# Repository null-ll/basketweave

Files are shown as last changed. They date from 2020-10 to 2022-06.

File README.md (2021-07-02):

# Basketweave
Basketweave

Through-hole Alice-style keyboard with arrow keys and a rotary encoder

### Default Layout
Default Layout
> View on [Keyboard Layout Editor](http://www.keyboard-layout-editor.com/#/gists/9b58a2c896b3cc25a28ef1dc43d93095) - for reference only

### BOM and Build Guide
[Build Guide](doc/build.md)

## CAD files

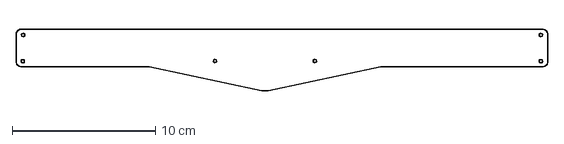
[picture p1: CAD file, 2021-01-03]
acrylic_guard.dxf
37.1 x 4.29 cm

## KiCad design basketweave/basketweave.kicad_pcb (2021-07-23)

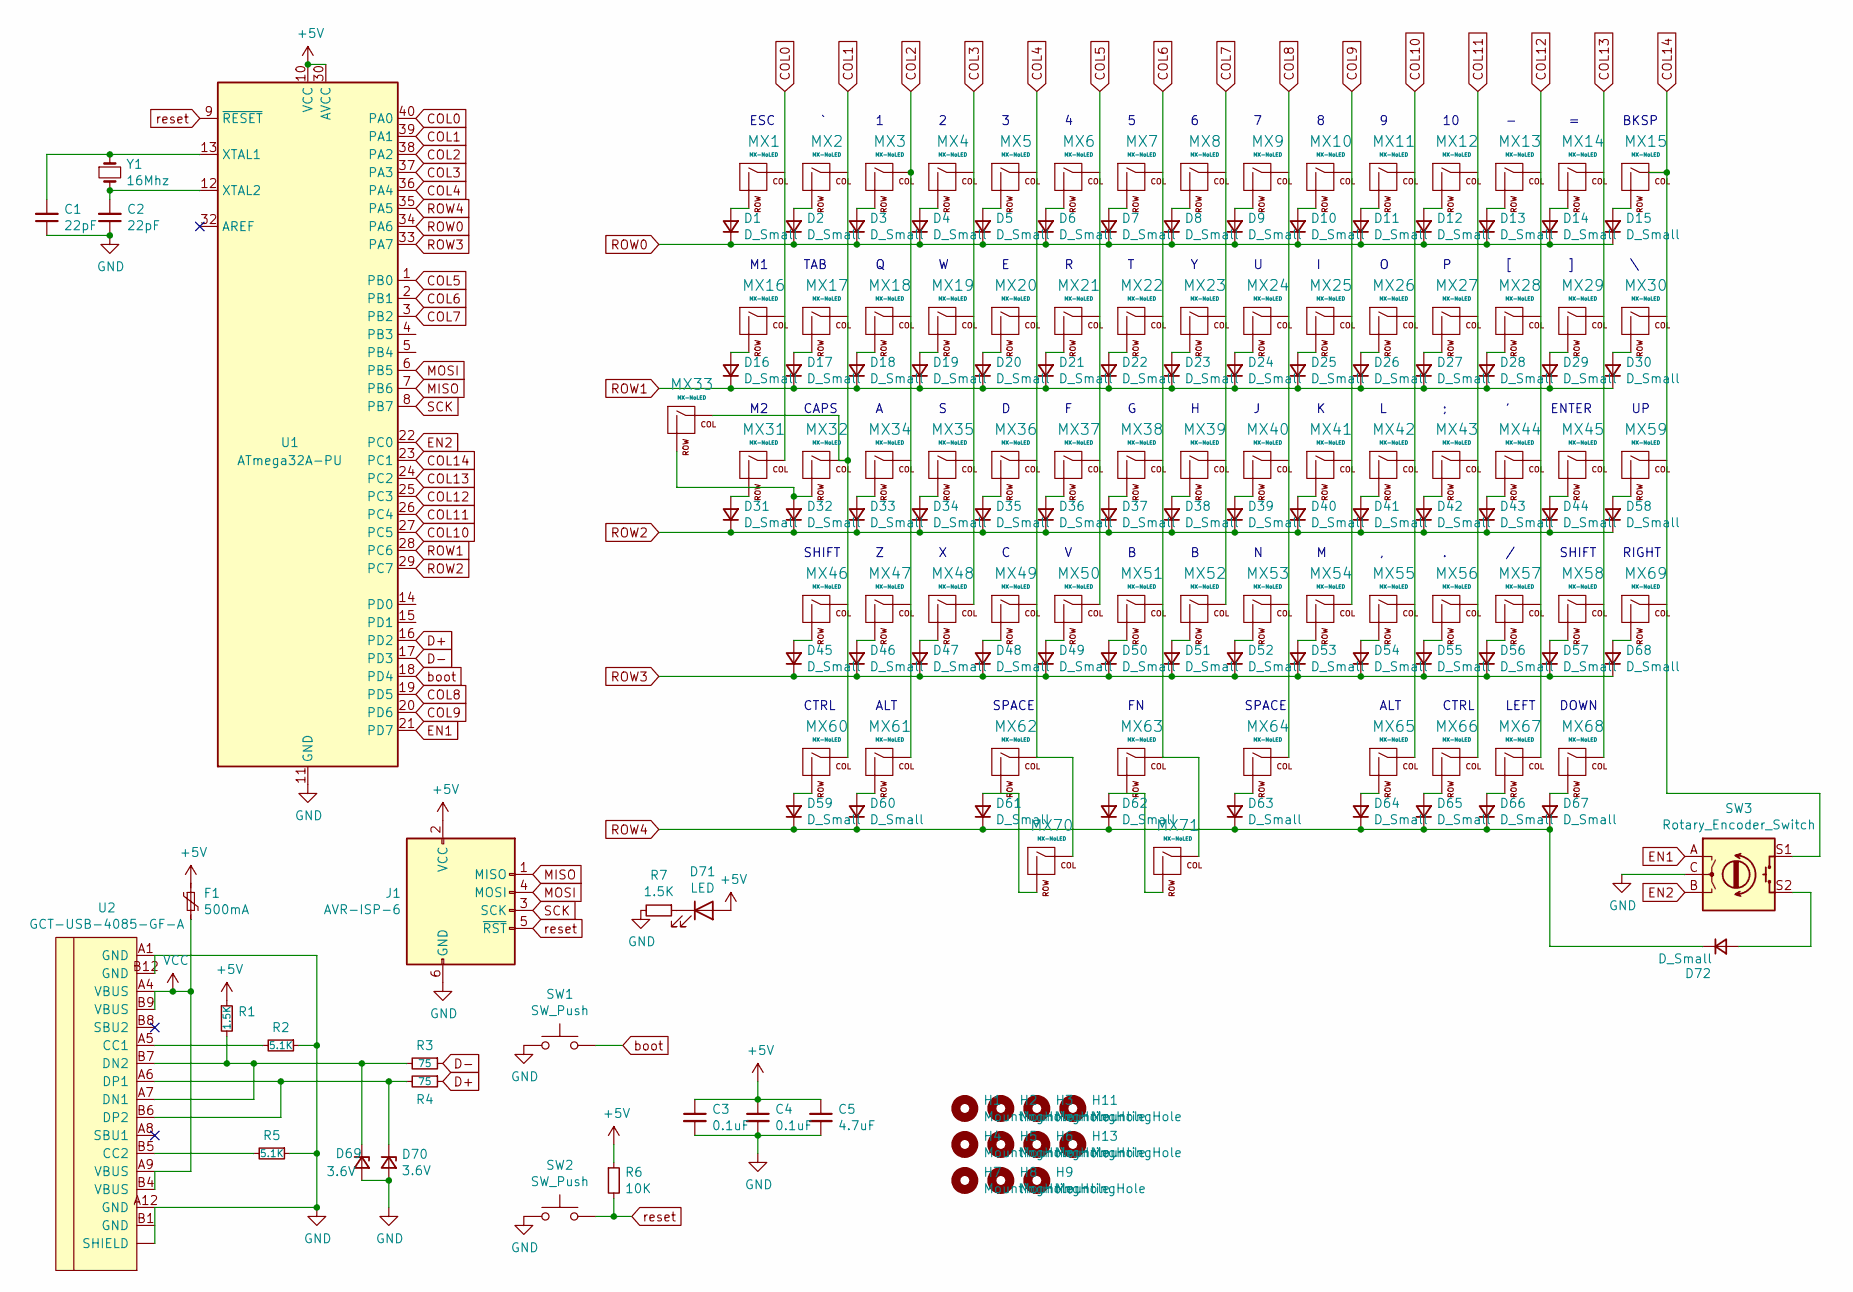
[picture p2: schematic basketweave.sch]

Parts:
C1, C2: 22pF; C_Disc_D3.0mm_W2.0mm_P2.50mm
C3, C4: 0.1uF; C_Disc_D4.3mm_W1.9mm_P5.00mm
C5: 4.7uF; CP_Radial_D4.0mm_P1.50mm
D1, D2, D3, D4, D5, D6, D7, D8, D9, D10, D11, D12, D13, D14, D15, D16, D17, D18, D19, D20, D21, D22, D23, D24, D25, D26, D27, D28, D29, D30, D31, D32, D33, D34, D35, D36, D37, D38, D39, D40, D41, D42, D43, D44, D45, D46, D47, D48, D49, D50, D51, D52, D53, D54, D55, D56, D57, D58, D59, D60, D61, D62, D63, D64, D65, D66, D67, D68, D72: D_Small; D_DO-35_SOD27_P7.62mm_Horizontal
D69, D70: 3.6V; D_DO-35_SOD27_P7.62mm_Horizontal
D71: LED; LED_D3.0mm_Clear
F1: 500mA; polyfuse_5.1mm
H1, H2, H3, H4, H5, H6, H7, H8, H9, H11, H13: MountingHole; MountingHole_2.2mm_M2_Pad
J1: AVR-ISP-6; PinHeader_2x03_P2.54mm_Vertical
MX1, MX2, MX3, MX4, MX5, MX6, MX7, MX8, MX9, MX10, MX11, MX12, MX13, MX14, MX16, MX18, MX19, MX20, MX21, MX22, MX23, MX24, MX25, MX26, MX27, MX28, MX29, MX31, MX34, MX35, MX36, MX37, MX38, MX39, MX40, MX41, MX42, MX43, MX44, MX47, MX48, MX49, MX50, MX51, MX52, MX53, MX54, MX55, MX56, MX57, MX59, MX67, MX68, MX69, MX71: MX-NoLED; MXOnly-1U-NoLED
MX15: MX-NoLED; MXOnly-2U-NoLED
MX17, MX30, MX60, MX61, MX65, MX66: MX-NoLED; MXOnly-1.5U-NoLED
MX32, MX63: MX-NoLED; MXOnly-1.25U-NoLED
MX33, MX58: MX-NoLED; MXOnly-1.75U-NoLED
MX45, MX46, MX70: MX-NoLED; MXOnly-2.25U-ReversedStabilizers-NoLED
MX62: MX-NoLED; MXOnly-2U-ReversedStabilizers-NoLED
MX64: MX-NoLED; MXOnly-2.75U-ReversedStabilizers-NoLED
R1, R7: 1.5K; R_Axial_DIN0204_L3.6mm_D1.6mm_P5.08mm_Horizontal
R2, R5: 5.1K; R_Axial_DIN0204_L3.6mm_D1.6mm_P5.08mm_Horizontal
R3, R4: 75; R_Axial_DIN0204_L3.6mm_D1.6mm_P5.08mm_Horizontal
R6: 10K; R_Axial_DIN0204_L3.6mm_D1.6mm_P5.08mm_Horizontal
SW1, SW2: SW_Push; SW_PUSH_6mm
SW3: Rotary_Encoder_Switch; RotaryEncoder_Alps_EC11E-Switch_Vertical_H20mm
U1: ATmega32A-PU; DIP-40_W15.24mm
U2: GCT-USB-4085-GF-A; USB_C_GCT_USB4085
Y1: 16Mhz; Crystal_HC49-4H_Vertical

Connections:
COL0: MX1.1 (COL), MX16.1 (COL), MX31.1 (COL), U1.40 (PA0)
COL1: MX2.1 (COL), MX17.1 (COL), MX32.1 (COL), MX33.1 (COL), MX46.1 (COL), MX60.1 (COL), U1.39 (PA1)
COL2: MX3.1 (COL), MX18.1 (COL), MX34.1 (COL), MX47.1 (COL), MX61.1 (COL), U1.38 (PA2)
COL3: MX4.1 (COL), MX19.1 (COL), MX35.1 (COL), MX48.1 (COL), U1.37 (PA3)
COL4: MX5.1 (COL), MX20.1 (COL), MX36.1 (COL), MX49.1 (COL), MX62.1 (COL), MX70.1 (COL), U1.36 (PA4)
COL5: MX6.1 (COL), MX21.1 (COL), MX37.1 (COL), MX50.1 (COL), U1.1 (PB0)
COL6: MX7.1 (COL), MX22.1 (COL), MX38.1 (COL), MX51.1 (COL), MX63.1 (COL), MX71.1 (COL), U1.2 (PB1)
COL7: MX8.1 (COL), MX23.1 (COL), MX39.1 (COL), MX52.1 (COL), U1.3 (PB2)
COL8: MX9.1 (COL), MX24.1 (COL), MX40.1 (COL), MX53.1 (COL), MX64.1 (COL), U1.19 (PD5)
COL9: MX10.1 (COL), MX25.1 (COL), MX41.1 (COL), MX54.1 (COL), U1.20 (PD6)
COL10: MX11.1 (COL), MX26.1 (COL), MX42.1 (COL), MX55.1 (COL), MX65.1 (COL), U1.27 (PC5)
COL11: MX12.1 (COL), MX27.1 (COL), MX43.1 (COL), MX56.1 (COL), MX66.1 (COL), U1.26 (PC4)
COL12: MX13.1 (COL), MX28.1 (COL), MX44.1 (COL), MX57.1 (COL), MX67.1 (COL), U1.25 (PC3)
COL13: MX14.1 (COL), MX29.1 (COL), MX45.1 (COL), MX58.1 (COL), MX68.1 (COL), U1.24 (PC2)
COL14: MX15.1 (COL), MX30.1 (COL), MX59.1 (COL), MX69.1 (COL), SW3.S1, U1.23 (PC1); also elsewhere on the board
D+: R4.1, U1.16 (PD2)
D-: R3.1, U1.17 (PD3)
EN1: SW3.A, U1.21 (PD7); also elsewhere on the board
EN2: SW3.B, U1.22 (PC0); also elsewhere on the board
GND: C1.1, C2.1, C3.2, C4.2, C5.2, D69.2 (A), D70.2 (A), J1.6 (GND), R2.1, R5.1, R7.2, SW1.1, SW2.1, SW3.C, U1.11 (GND), U1.31 (GND), U2.A1 (GND), U2.A12 (GND), U2.B12 (GND), U2.~ (SHIELD); also elsewhere on the board
MISO: J1.1 (MISO), U1.7 (PB6); also elsewhere on the board
MOSI: J1.4 (MOSI), U1.6 (PB5); also elsewhere on the board
unnamed: C1.2, U1.13 (XTAL1), Y1.1
unnamed: C2.2, U1.12 (XTAL2), Y1.2
unnamed: D1.2 (A), MX1.2 (ROW)
unnamed: D2.2 (A), MX2.2 (ROW)
unnamed: D3.2 (A), MX3.2 (ROW)
unnamed: D4.2 (A), MX4.2 (ROW)
unnamed: D5.2 (A), MX5.2 (ROW)
unnamed: D6.2 (A), MX6.2 (ROW)
unnamed: D7.2 (A), MX7.2 (ROW)
unnamed: D8.2 (A), MX8.2 (ROW)
unnamed: D9.2 (A), MX9.2 (ROW)
unnamed: D10.2 (A), MX10.2 (ROW)
unnamed: D11.2 (A), MX11.2 (ROW)
unnamed: D12.2 (A), MX12.2 (ROW)
unnamed: D13.2 (A), MX13.2 (ROW)
unnamed: D14.2 (A), MX14.2 (ROW)
unnamed: D15.2 (A), MX15.2 (ROW)
unnamed: D16.2 (A), MX16.2 (ROW)
unnamed: D17.2 (A), MX17.2 (ROW)
unnamed: D18.2 (A), MX18.2 (ROW)
unnamed: D19.2 (A), MX19.2 (ROW)
unnamed: D20.2 (A), MX20.2 (ROW)
unnamed: D21.2 (A), MX21.2 (ROW)
unnamed: D22.2 (A), MX22.2 (ROW)
unnamed: D23.2 (A), MX23.2 (ROW)
unnamed: D24.2 (A), MX24.2 (ROW)
unnamed: D25.2 (A), MX25.2 (ROW)
unnamed: D26.2 (A), MX26.2 (ROW)
unnamed: D27.2 (A), MX27.2 (ROW)
unnamed: D28.2 (A), MX28.2 (ROW)
unnamed: D29.2 (A), MX29.2 (ROW)
unnamed: D30.2 (A), MX30.2 (ROW)
unnamed: D31.2 (A), MX31.2 (ROW)
unnamed: D32.2 (A), MX32.2 (ROW), MX33.2 (ROW)
unnamed: D33.2 (A), MX34.2 (ROW)
unnamed: D34.2 (A), MX35.2 (ROW)
unnamed: D35.2 (A), MX36.2 (ROW)
unnamed: D36.2 (A), MX37.2 (ROW)
unnamed: D37.2 (A), MX38.2 (ROW)
unnamed: D38.2 (A), MX39.2 (ROW)
unnamed: D39.2 (A), MX40.2 (ROW)
unnamed: D40.2 (A), MX41.2 (ROW)
unnamed: D41.2 (A), MX42.2 (ROW)
unnamed: D42.2 (A), MX43.2 (ROW)
unnamed: D43.2 (A), MX44.2 (ROW)
unnamed: D44.2 (A), MX45.2 (ROW)
unnamed: D45.2 (A), MX46.2 (ROW)
unnamed: D46.2 (A), MX47.2 (ROW)
unnamed: D47.2 (A), MX48.2 (ROW)
unnamed: D48.2 (A), MX49.2 (ROW)
unnamed: D49.2 (A), MX50.2 (ROW)
unnamed: D50.2 (A), MX51.2 (ROW)
unnamed: D51.2 (A), MX52.2 (ROW)
unnamed: D52.2 (A), MX53.2 (ROW)
unnamed: D53.2 (A), MX54.2 (ROW)
unnamed: D54.2 (A), MX55.2 (ROW)
unnamed: D55.2 (A), MX56.2 (ROW)
unnamed: D56.2 (A), MX57.2 (ROW)
unnamed: D57.2 (A), MX58.2 (ROW)
unnamed: D58.2 (A), MX59.2 (ROW)
unnamed: D59.2 (A), MX60.2 (ROW)
unnamed: D60.2 (A), MX61.2 (ROW)
unnamed: D63.2 (A), MX64.2 (ROW)
unnamed: D64.2 (A), MX65.2 (ROW)
unnamed: D65.2 (A), MX66.2 (ROW)
unnamed: D66.2 (A), MX67.2 (ROW)
unnamed: D67.2 (A), MX68.2 (ROW)
unnamed: D68.2 (A), MX69.2 (ROW)
unnamed 90: D69.1 (K), R1.2, R3.2, U2.A7 (DN1), U2.B7 (DN2); also elsewhere on the board
unnamed 91: D70.1 (K), R4.2, U2.A6 (DP1), U2.B6 (DP2); also elsewhere on the board
unnamed 92: R2.2, U2.A5 (CC1); also elsewhere on the board
unnamed 93: R5.2, U2.B5 (CC2); also elsewhere on the board
ROW0: D1.1 (K), D2.1 (K), D3.1 (K), D4.1 (K), D5.1 (K), D6.1 (K), D7.1 (K), D8.1 (K), D9.1 (K), D10.1 (K), D11.1 (K), D12.1 (K), D13.1 (K), D14.1 (K), D15.1 (K), U1.34 (PA6)
ROW1: D16.1 (K), D17.1 (K), D18.1 (K), D19.1 (K), D20.1 (K), D21.1 (K), D22.1 (K), D23.1 (K), D24.1 (K), D25.1 (K), D26.1 (K), D27.1 (K), D28.1 (K), D29.1 (K), D30.1 (K), U1.28 (PC6)
ROW2: D31.1 (K), D32.1 (K), D33.1 (K), D34.1 (K), D35.1 (K), D36.1 (K), D37.1 (K), D38.1 (K), D39.1 (K), D40.1 (K), D41.1 (K), D42.1 (K), D43.1 (K), D44.1 (K), D58.1 (K), U1.29 (PC7)
ROW3: D45.1 (K), D46.1 (K), D47.1 (K), D48.1 (K), D49.1 (K), D50.1 (K), D51.1 (K), D52.1 (K), D53.1 (K), D54.1 (K), D55.1 (K), D56.1 (K), D57.1 (K), D68.1 (K), U1.33 (PA7)
SCK: J1.3 (SCK), U1.8 (PB7); also elsewhere on the board
VCC: F1.2, U2.A4 (VBUS), U2.A9 (VBUS), U2.B4 (VBUS), U2.B9 (VBUS); also elsewhere on the board
boot: SW1.2, U1.18 (PD4); also elsewhere on the board
reset: J1.5 (~RST), R6.2, SW2.2, U1.9 (~RESET); also elsewhere on the board

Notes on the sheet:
ESC
BKSP
ENTER
CAPS
SHIFT
CTRL
ALT
SPACE
LEFT
DOWN
RIGHT
TAB

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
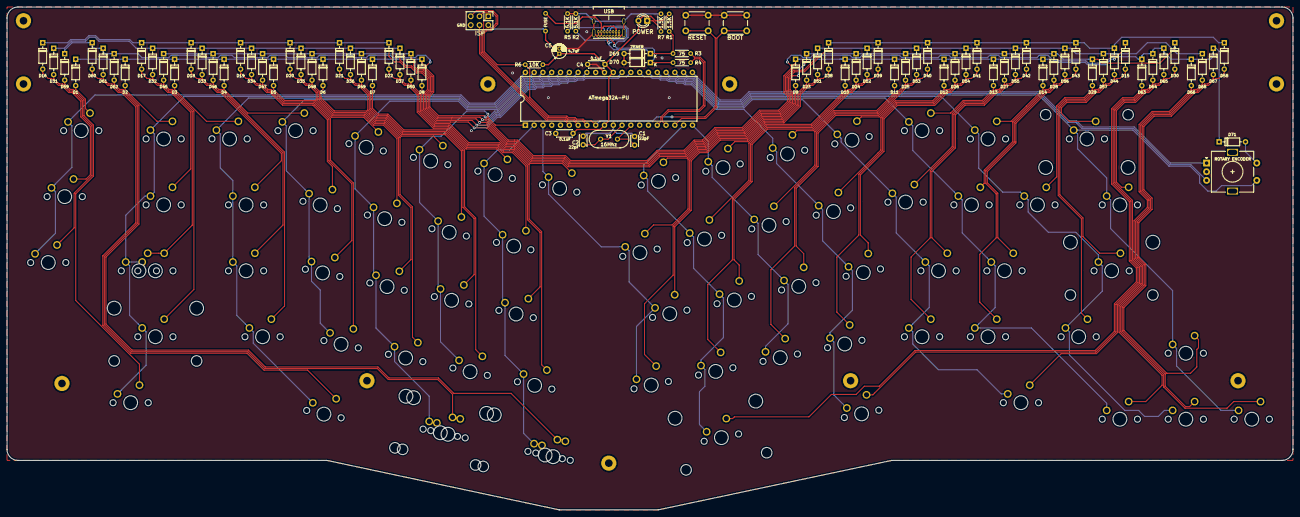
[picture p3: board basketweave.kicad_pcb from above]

Board: 2 copper layers, 371.5 x 145.3 mm, 174 parts (0 on the bottom side), 108 nets.

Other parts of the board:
BOOT: SW_Push; SW_PUSH_6mm
ISP: AVR-ISP-6; PinHeader_2x03_P2.54mm_Vertical
POWER: LED; LED_D3.0mm_Clear
RESET: SW_Push; SW_PUSH_6mm
ROTARY ENCODER: Rotary_Encoder_Switch; RotaryEncoder_Alps_EC11E-Switch_Vertical_H20mm
USB: GCT-USB-4085-GF-A; USB_C_GCT_USB4085

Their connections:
COL14: ROTARY ENCODER.S1; also elsewhere on the board
EN1: ROTARY ENCODER.A; also elsewhere on the board
EN2: ROTARY ENCODER.B; also elsewhere on the board
GND: BOOT.1, ISP.6, RESET.1, ROTARY ENCODER.C, USB.A1, USB.A12, USB.B1, USB.B12, USB.S1; also elsewhere on the board
MISO: ISP.1; also elsewhere on the board
MOSI: ISP.4; also elsewhere on the board
unnamed 90: USB.A7, USB.B7; also elsewhere on the board
unnamed 91: USB.A6, USB.B6; also elsewhere on the board
unnamed 92: USB.A5; also elsewhere on the board
unnamed 93: USB.B5; also elsewhere on the board
SCK: ISP.3; also elsewhere on the board
VCC: USB.A4, USB.A9, USB.B4, USB.B9; also elsewhere on the board
boot: BOOT.2; also elsewhere on the board
reset: ISP.5, RESET.2; also elsewhere on the board

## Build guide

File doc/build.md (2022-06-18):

# Build Guide

## Required Components
You will need the following tools and components to build the Basketweave (not included in the kit):
- Soldering iron and solder
- Phillips head screwdriver
- Flush side cutters
- No-clean flux (recommended to prevent bridging on USB pins)
- 68 MX style switches
- 5 PCB mount 2u stabilizers
- Keycaps (check compatibility, this layout uses many non-standard keys)
- USB Type C cable
## Included Components
The following components are included in the Basketweave keyboard kit:
kit
| Ref | Component | Qty | Notes |
| --- | --- | --- | ----- |
| C1, C2  | 22pF Capacitor | 2 
| C3, C4  | 0.1uF Capacitor | 2
| C5 | 4.7uF Capacitor | 1 | The footprint on the PCB is meant for an electrolytic capacitor - ceramic will work but will be awkward to fit.
| D1-68, D72 | 1n4148 Diode | 69
| D69, D70 | 3.6V Zener Diode | 2  | Keep separate from the 1n4148 diodes
| FUSE | 500mA Resettable fuse  | 1
| ISP | 6 pin header | 1
| USB | GCT USB4085 USB C port | 1
| POWER | 3mm LED | 1
| R1, R7  | 1.5k Resistor | 2 | Make sure to get 1/8 Watt resistors since 1/4 (a common power rating) is too big for the footprint.
| R2, R5  | 5.1k Resistor | 2 
| R3, R4  | 75 Resistor | 2 
| R6 | 10k Resistor | 1 
| U1 | ATmega32A | 1
| | 40 pin IC socket | 1
| RESET, BOOT | 6mm push button | 1
| Y1 | 16MHz Crystal | 1
| | EC11 Rotary encoder | 1
| | Knob | 1
| | M2 6mm standoff | 11
| | M2 10+3mm standoff | 6
| | M2 6mm screw | 6
| | M2 4mm screw | 16
| | Rubber Feet | 4
| | Basketweave PCB | 1
| | Bottom Plate | 1
| | Switch plate | 1

### Step 1. Zener Diodes (D69, D70)
**This part has specific orientation** - black line on the diode lines up with the square pad (points right)
Zener Diodes

### Step 2. Resistors (R1-7)
Orientation does not matter. Solder based on the labeled values.
| Ref | Value |
| --- | ----- |
| R1, R7 | 1.5k  |
| R2, R5 | 5.1k  |
| R3, R4 | 75 |
| R6 | 10k |
Resistors

### Step 3. 1n1418 Diodes (D1-68, D72)
**This part has a specific orientation** - black line on the diode lines up with the square pad (points up)
Diodes

### Step 4. Capacitors (C1-4)
Orientation does not matter. Solder based on the labeled values.
| Ref | Value |
| --- | ----- |
| C1, C2 | 22uF  |
| C3, C4 | 0.1uF |
Capacitors

### Step 5. USB Port
Solder one of the large legs first and check that the port is flush before soldering the other three legs. \
Solder the smaller pins by applying no-clean flux across the pins, then drag a small amount of solder across the pins until all the holes are filled.
USB port

### Step 6. Capacitor (C5)
**This part has a specific orientation** - longer leg goes in square pad (white mark on the capacitor points up)
Capacitor

### Step 7. Fuse
Orientation does not matter. Fold down after soldering.
Fuse

### Step 8. Crystal (Y1)
Orientation does not matter.
Crystal

### Step 9. LED
**This part has a specific orientation** - shorter leg and flat side of the LED line up with the square pad
LED

### Step 10. Push Button (RESET, BOOT) and IC Socket
Push buttons have no specific orientation. \
Align the notch on the IC Socket with the markings on the PCB. 
Push button and IC socket

### Step 11. Pin Header
Orientation does not matter. Longer pins on top.
Pin header

### Step 12. ATmega32A
Insert ATmega32A into the IC socket. Make sure the notch on the microcontroller aligns with the notch in the IC socket and the markings on the PCB.

### Step 13. M2 6mm Standoffs, M2 10+3mm Standoffs, M2 4mm screws
| Component | Qty | Location |
| --- | --- | --- |
| M2 10+3mm standoff | 6 | Front top |
| M2 4mm screws | 5 | Front bottom |
| M2 6mm standoff | 11  | Back |
Screws

### Step 14. Switches and Rotary Encoder
Install the stabilizers, then place the plate on top. \
Install and solder switches and rotary encoder.
Switches

### Step 15. Bottom Plate
(optional) Flip the board over and insert foam. Screw angling feet into the bottom plate. \
Screw in bottom plate using 11x M2 4mm screws. \
Attach rubber feet.
Foam
Bottom plate

### Step 16. Acrylic Guard
Screw in acrylic guard using 6x M2 6mm screws. Be careful not to overtighten.
Acrylic

### Step 17. Keycaps
Add keycaps.
Keycaps

Done!

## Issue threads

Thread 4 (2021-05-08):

Reset button doesnt't work

CGMossa, 2021-05-08:
I've assembled the basketweave.
The reset button makes a noise as if it went to bootloader-mode, but it doesn't do that really.
But if one use the FN + R = Reset, then that works and the keyboard goes fully into bootloader mode.

Any troubleshoot ideas?

Also

* Is there a Keyboard layout that is updated? The one link in [README.md](README.md) doesn't link to the right
layout.
* The qmk configurator isn't setup for the knob -- yet?

null-ll, 2021-05-08:
To enter bootloader mode, try holding down the BOOT button, tap the RESET button, then let go of both.

I've fixed the [keyboard layout](http://www.keyboard-layout-editor.com/#/gists/9b58a2c896b3cc25a28ef1dc43d93095) link. Thanks for pointing it out. I can't guarantee that the layout is 100% accurate with the distances and locations since I have never had any plates cut using the layout file.

As far as I know, QMK configurator doesn't support configurating encoders, so you'll have to do this through the firmware files or by using a program like [Vial](https://get.vial.today/).

CGMossa, 2021-05-08:
Very cool. I'll close this.

Closed 2021-05-08.

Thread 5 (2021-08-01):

D72 is shown on PCB, but never referenced in build guide.

lou00011, 2021-08-01:
Above rotary encoder is D72. D72 is never referenced in the build guide, however D71 appears in Step 3, but I cannot find it in on the actual board.

Can you confirmed that this is a typo? That in addition to D1-D68 for 1n4148 diode, you are supposed to use it for slot above rotary encoder?

null-ll, 2021-08-01:
Yes, the slot above the rotary encoder is for a 1n4148 diode. The label D72 was a mistake from an earlier version of the board and was replaced with D71.

lou00011, 2021-08-01:
Resolved.

Closed 2021-08-01.

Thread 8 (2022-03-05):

bootloader error

F1hone, 2022-03-05:
hello，me again
Sorry to bother you..
I encountered a little problem when flashing the boot loader, when I try to use qmk msys to make the hex file of the bootloader, an error will be reported, resulting in I can't flash in, it's been bugging me for days,

F1hone, 2022-03-05:
This is the information of the terminal,
please help me to see it, if you can give me a little help, I will be very grateful to you,
{I use usbasp},thanks a lot

[CHK@DESKTOP-3QEGFU6 32a]$ cd /m/Desktop/USBaspLoader-atmega32a
[CHK@DESKTOP-3QEGFU6 USBaspLoader-atmega32a]$ make
.
.
======>BUILDING BOOTLOADER FIRMWARE
.
make[1]: 进入目录“/m/Desktop/USBaspLoader-atmega32a/firmware”
main.c: In function 'main':
: warning: function declared 'noreturn' has a 'return' statement
.
.
.
!!!ATTANTION!!!
(data+text) MUST fit into your MCUs bootloader section
.
text data bss dec hex filename
2136 6 55 2197 895 main.elf
.
.
.
make[1]: 离开目录“/m/Desktop/USBaspLoader-atmega32a/firmware”
.
.
======>BUILDING BOOTLOADER UPDATER (EXPERIMENTAL)
.
make[1]: 进入目录“/m/Desktop/USBaspLoader-atmega32a/updater”
In file included from updater.c:8:
usbasploader.h:20:14: warning: duplicate 'const' declaration specifier [-Wduplicate-decl-specifier]
extern const const uint16_t usbasploader[SIZEOF_new_firmware>>1] PROGMEM;
^~~~~
updater.c:53:4: warning: #warning I do not know where new "bootloader__do_spm" is located - assuming "NEW_BOOTLOADER_ADDRESS+(funcaddr___bootloader__do_spm % SPM_PAGESIZE)" [-Wcpp]
#warning I do not know where new "bootloader__do_spm" is located - assuming "NEW_BOOTLOADER_ADDRESS+(funcaddr___bootloader__do_spm % SPM_PAGESIZE)"
^~~~~~~
updater.c:61:4: warning: #warning "TEMP_SPM_PAGEADR" is not defined explicitly - will choose END OF FLASH ! [-Wcpp]
#warning "TEMP_SPM_PAGEADR" is not defined explicitly - will choose END OF FLASH !
^~~~~~~
.
.
text data bss dec hex filename
3102 2 0 3104 c20 updater.elf
.
make[1]: 离开目录“/m/Desktop/USBaspLoader-atmega32a/updater”
[CHK@DESKTOP-3QEGFU6 USBaspLoader-atmega32a]$

null-ll, 2022-03-05:
There shouldn't be an issue. The firmware seems to have been built successfully, as shown in the first half of the output. The second half is not used and can be ignored.

F1hone, 2022-03-18:
Thank you for your reply,
I tried to use commands other than "make flash" to burn the bootloader into the chip, the result was successful,
Then I tried to build my own keyboard hex file using your bootloader for the 32a chip, and it failed. There are very few tutorials on how to customize the bootloader on the Internet. I can only learn from other people's firmware, but I still don't understand the meaning of many of the values. . This is too hard for me as a beginner, can you give me some guidance? Thank you very much.

null-ll, 2022-03-19:
If you are able to successfully burn the bootloader onto the chip, the keyboard should be detected by QMK toolbox. You can just flash your keyboard hex file from there.

Closed 2023-03-07.

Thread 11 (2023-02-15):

Keyboard case/wrist rest compatability

psaju, 2023-02-15:
First od all, thank you for releasing this keyboard! I found it very enjoyable to build and to use.

I would like to ask about the shape of the keyboard - is it identical to any existing keyboard, like the Alice or Keychron Q8? I'm having trouble finding a wrist rest and/or case that would fit and cannot find any definitive answers.

null-ll, 2023-02-17:
Sorry, the shape is not identical to any other existing boards that I know of. There are acrylic cases available from a few sellers online, though they are mostly custom order.

Closed 2023-02-17.

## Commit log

2020-09-20 added all files
    [keyboard-B_Cu.gbr, keyboard-B_Mask.gbr, keyboard-B_Paste.gbr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]
2020-10-18 renamed to 'basketweave'
    [basketweave.kicad_pcb, basketweave.sch, basketweave_bottom.kicad_pcb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]
2020-10-24 changed logo, name, and pattern design
    [basketweave-B_Cu.gbr, basketweave-B_Mask.gbr, basketweave-B_Paste.gbr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]
2020-10-24 added switch size markings
    [basketweave-B_Cu.gbr, basketweave-B_Mask.gbr, basketweave-B_Paste.gbr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]
2020-11-04 added diode for rotary encoder switch
    [basketweave.kicad_pcb]
2020-12-02 Added acrylic guard
    [acrylic_guard.dxf]
2021-01-10 fixed missing symbols
    [basketweave.sch]
2021-01-23 fix sch
    [basketweave-B_Cu.gbr, basketweave-B_Mask.gbr, basketweave-B_Paste.gbr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]
2021-07-23 fixed inaccurate label
    [basketweave-B_Cu.gbr, basketweave-B_Mask.gbr, basketweave-B_Paste.gbr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]
2022-06-15 Add note about resistor sizing and capacitor type
